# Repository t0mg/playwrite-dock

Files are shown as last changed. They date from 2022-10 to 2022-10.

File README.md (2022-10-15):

# Playwrite dock

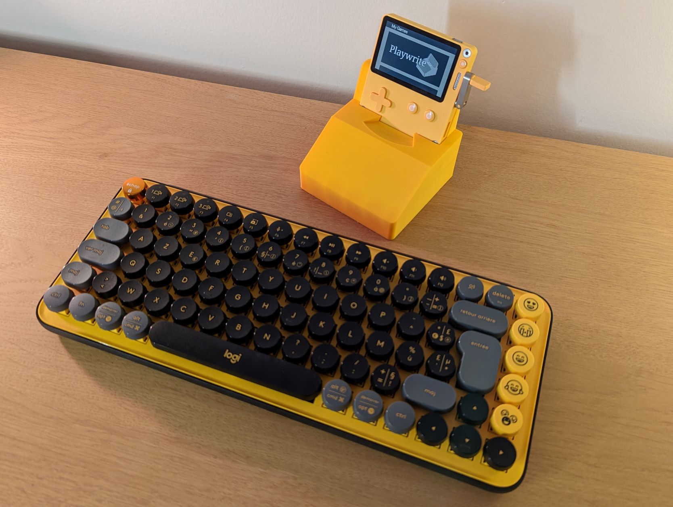
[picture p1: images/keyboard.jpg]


A keyboard and gamepad adapter dock for [Playdate](https://play.date), mainly designed for use with the [Playwrite experimental word processor](https://github.com/t0mg/playwrite), but compatible with any other Playdate game or app.

**Overview thread with demo videos: https://twitter.com/t0m_fr/status/1576949261849149440**

This repo is dedicated to the dock; it contains: 
- Source code for the Teensy microcontroller board (as a PlatformIO project)
- CAD and STL files for the 3d-printed dock (see [here](https://github.com/t0mg/playwrite-dock/tree/master/dock) for pictures and instructions)

For the Playwrite app for Playdate, see [here](https://github.com/t0mg/playwrite).

## Dock overview

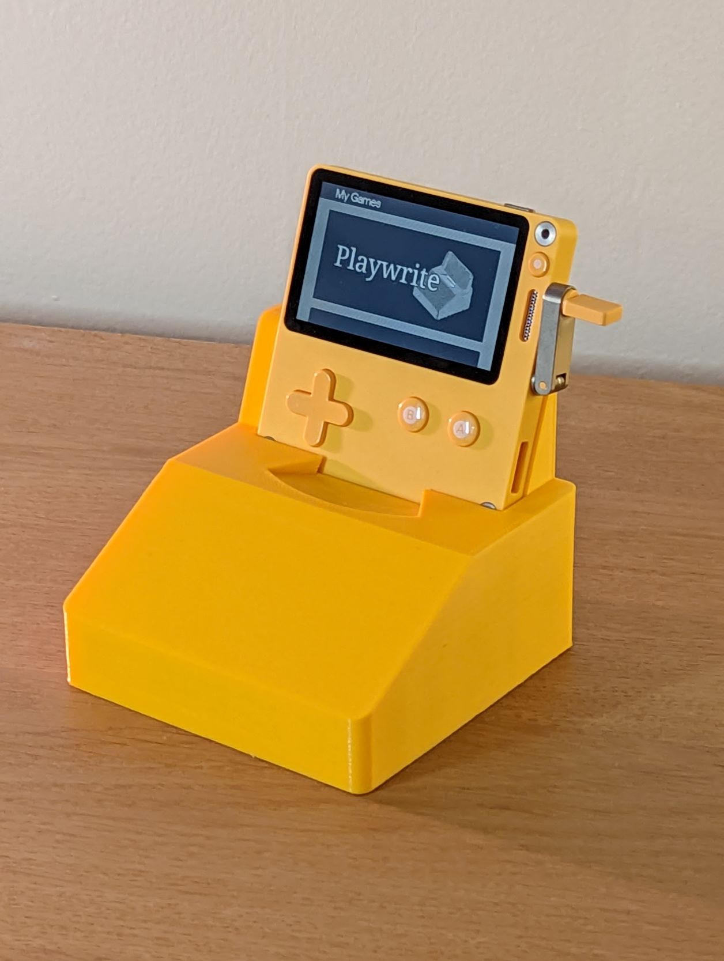
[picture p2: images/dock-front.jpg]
Bottom view of the dock assembly.
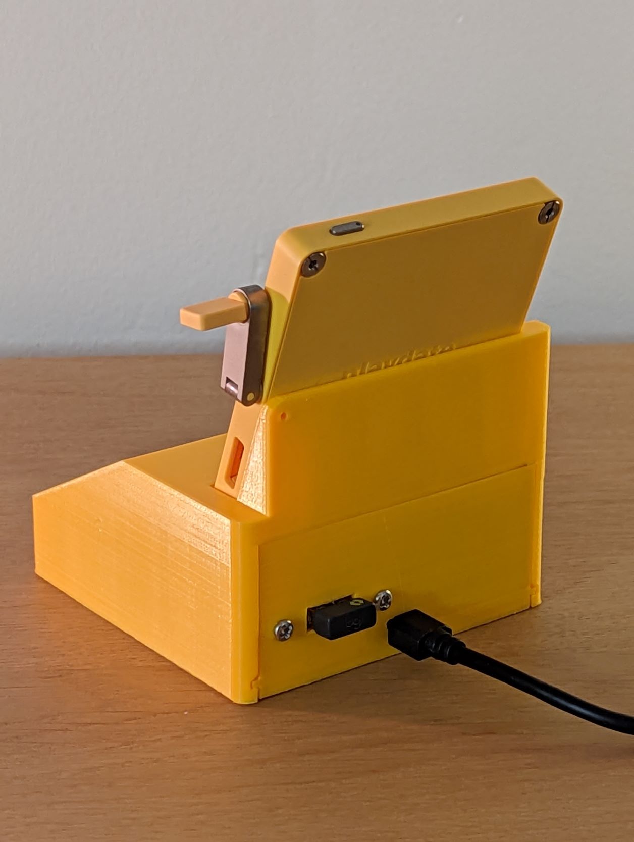
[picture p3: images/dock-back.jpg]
Bottom view of the dock assembly.
  

The dock is powered by a [Teensy 4.1 microcontroller](https://www.pjrc.com/store/teensy41.html). The USB Host port of the Teensy is used to connect to both a [Playdate](https://play.date/) console and a USB HID keyboard (or gamepad). It reads user inputs from these devices and uses USB Serial to communicate with the Playdate, leveraging a few of the available [USB commands](https://github.com/jaames/playdate-reverse-engineering/blob/main/usb/usb.md#usb-commands) to emulate native inputs, and listening to messages from the Playdate and [Playwrite app]((https://github.com/t0mg/playwrite)). 

The micro USB port of the Teensy is used to power the dock and flash the software. The dock also charges the Playdate though the Teensy (albeit slowly).

## Keyboard in controller mode

Arrow keys, Enter and Escape are directly mapped to the directions, A and B buttons respectively (and so are the A and S keys when not in the dedicated [Playwrite app](https://github.com/t0mg/playwrite). So the keyboard can be used anywhere in the OS or in games that don't rely on the crank (not because it's unusable; but because it's just not convenient).

## Full keyboard mode

The Playwrite app sends a specific command to the serial console (`KeyboardInputEnable`) to let the Teensy know that it can enable the "keyboard mode". In this mode,  keyspresses are encoded as `crankchange` angles in the dock (and decoded back to chars in the Playwrite app on the Playdate).

## USB Gamepad

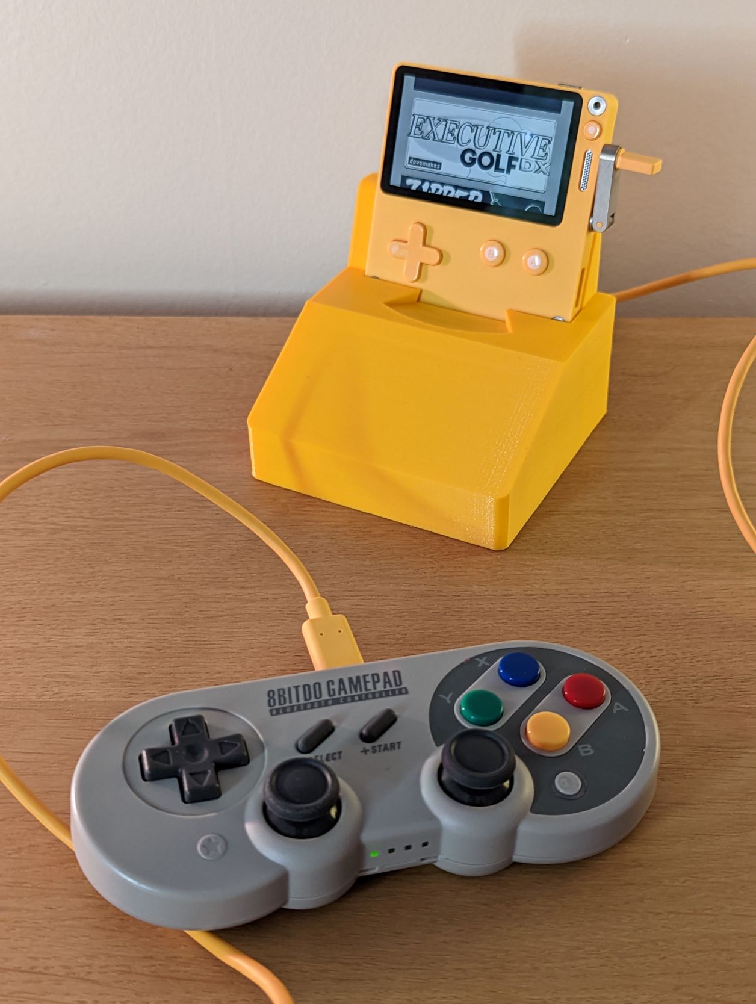
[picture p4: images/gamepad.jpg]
The dock connected over USB to an 8bitdo gamepad.


The dock software also supports USB Gamepads to some extent (tested on a couple of 8bitdo devices). This part of the project might arguably the most generally useful, as it could improve accessiblity of the device without the need of a full computer. 

TODO: Cranking via the gamepad is not supported. Mapping the right analog stick to the crank would be nice.

TODO: Bluetooth is not supported but is likely doable thanks to the [USBHost_t36](https://github.com/PaulStoffregen/USBHost_t36) library.

## BOM

It's a relatively cheap project. You'll need:

- A Teensy 4.1 microcontroller, with 4 pin header solderd to the USB Host port
- A USB 2.0 Hub
- Cables to connect your USB devices (Playdate, keyboard)

The exact references I used are linked in the [dock assembly page](https://github.com/t0mg/playwrite-dock/tree/master/dock#readme).

Additionally you'll need access to a 3d printer if you want to print the dock itself.

## Credits

Made possible by
- https://github.com/jaames/playdate-reverse-engineering
- https://www.pjrc.com/store/teensy41.html

Dependencies
- [USBHost_t36](https://github.com/PaulStoffregen/USBHost_t36) library
- [CircularBuffer](https://github.com/rlogiacco/CircularBuffer) library

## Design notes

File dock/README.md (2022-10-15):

# Playwrite dock CAD files

This folder contains the FCStd ([FreeCAD](https://www.freecadweb.org/)) [project file](https://github.com/t0mg/playwrite-dock/blob/master/dock/playwrite%20dock.FCStd) for the dock, as well as 3 STL exports (one for each part) ready for slicing.

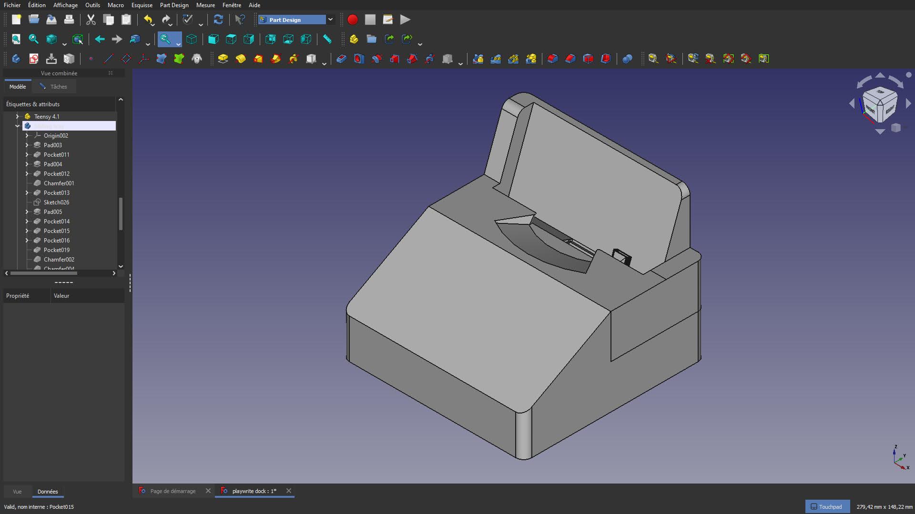
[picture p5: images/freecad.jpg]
FreeCAD screenshot.


## Printing

I loaded the 3 STL files into Cura and sliced them as a single print job, at 0.2mm layers using AA0.8 print core for support and AA0.4 core for the parts. It took 9 hours on an Ultimaker 3. Regardless of your printer and settings, supports are necessary for this print.

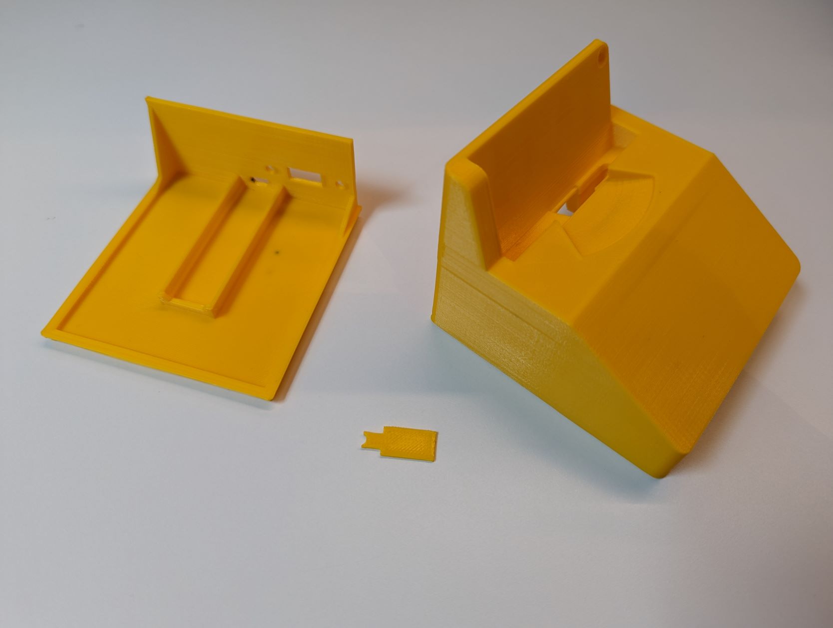
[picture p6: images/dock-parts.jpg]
The 3 parts of the dock, printed and cleaned up.


## Assembly

The project is designed to be very easy to assemble. The dock could be made quite a bit slimmer by using custom-built cables at the cost of requiring a lot more soldering.

### 1. USB C connector

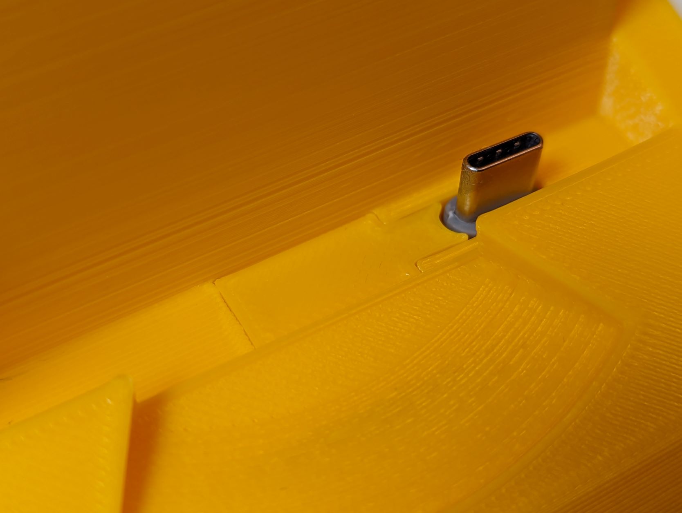
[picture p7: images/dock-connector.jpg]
Close-up view of the USB C connector protruding from the assembled dock.


This dock was designed specifically for [this USB A to angled USB C cable](https://www.amazon.fr/gp/product/B07H95NY5Y). The USB C male connector slides in the dedicated slot in the main part of the dock, then the small cover piece can be press-fit from the top to hide the opening.
    
### 2. Teensy

The bottom tray is designed to host the [Teensy 4.1](https://www.pjrc.com/store/teensy41.html) development board. It's a snug fit, insert the USB connector into the hole first, then press the Teensy down into the tray. Access the SD card slot was preserved, even though this project doesn't use it. You'll need to solder a 4 pin header connector to the USB host port prior to installing the Teensy.

### 3. USB hub

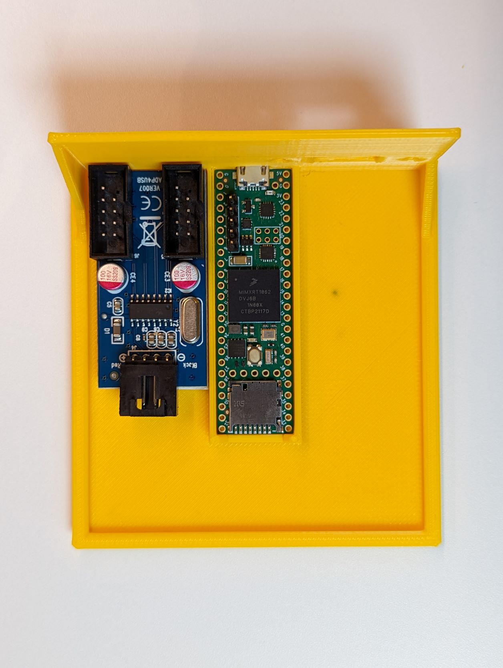
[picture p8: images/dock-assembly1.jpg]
The Teensy and USB C hub sitting in the bottom tray of the dock.


To connect more than 1 device at a time, I used [this USB 2.0 Hub](https://www.amazon.fr/gp/product/B088H6221R) intended for desktop PCs, which connects to the Teensy header. It came with doublesided tape, which makes positioning it in the dock tray very straightforward.

### 4. USB sockets

Finally I used [standard USB extension ports](https://www.amazon.fr/gp/product/B06XCVSPZ1) also meant for desktop PCs. You only need one of these cables since they have 2 USB connectors each. One goes to the tray's backplate and is held by the 2 original screws, it will host the gamepad or keyboard. The other remains inside the dock and connects to the Playdate via the USB A to USB C cable. The tray can then be slid into the upper piece of the dock (no locking system, it is tight enough to hold in place by itself).

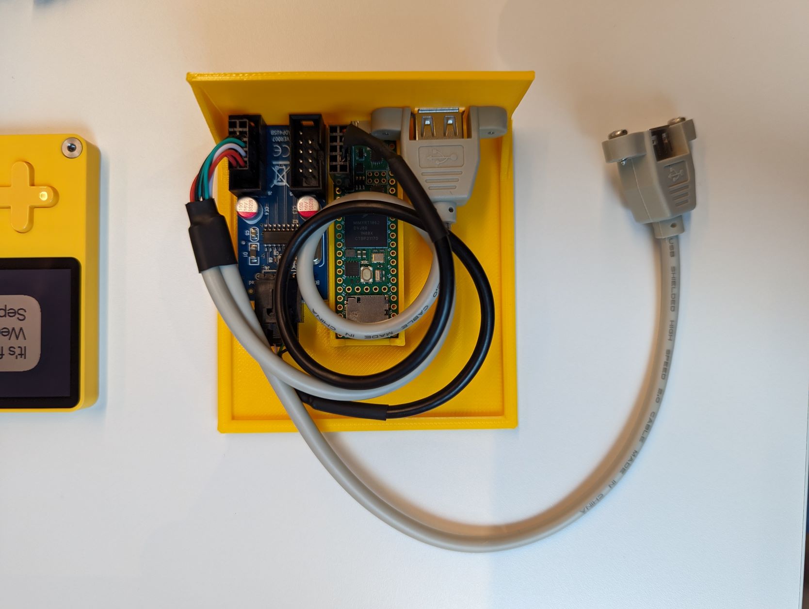
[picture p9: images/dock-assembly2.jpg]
Closing the tray under the dock.
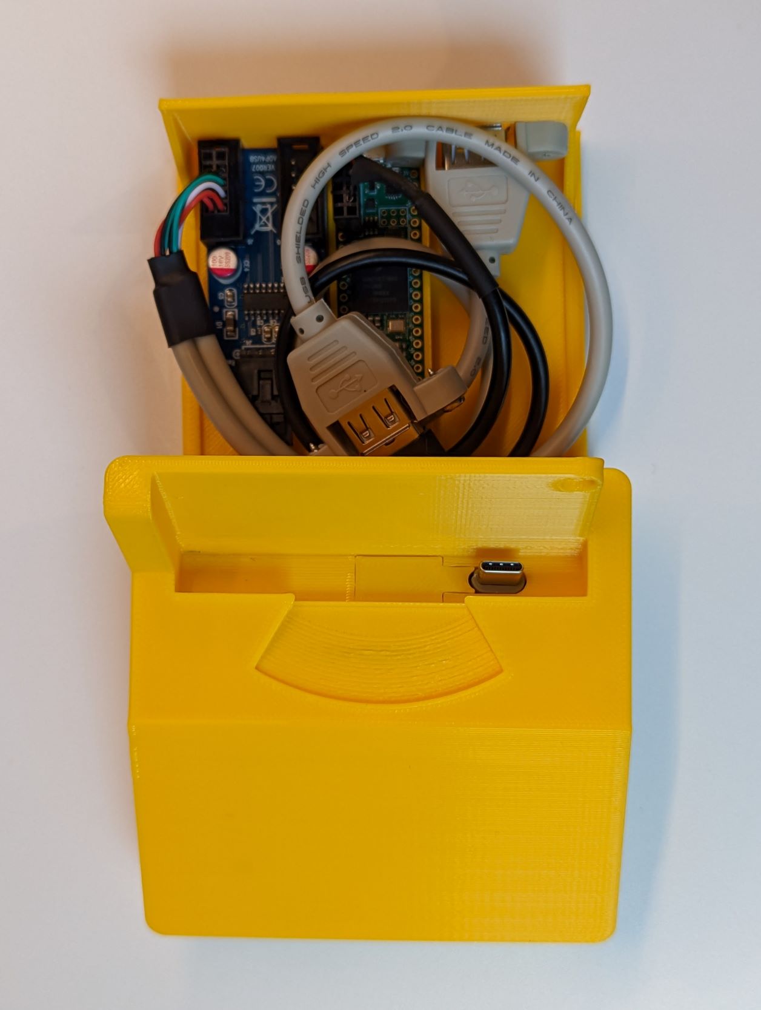
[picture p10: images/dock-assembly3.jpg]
USB cables installed in the tray.
 

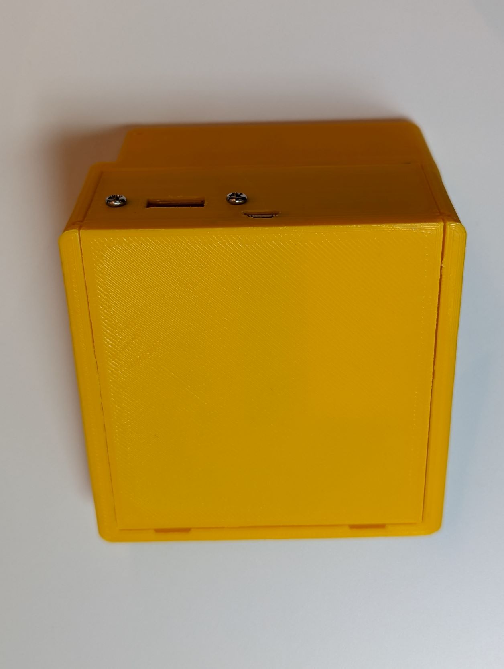
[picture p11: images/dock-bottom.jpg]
Bottom view of the dock assembly.
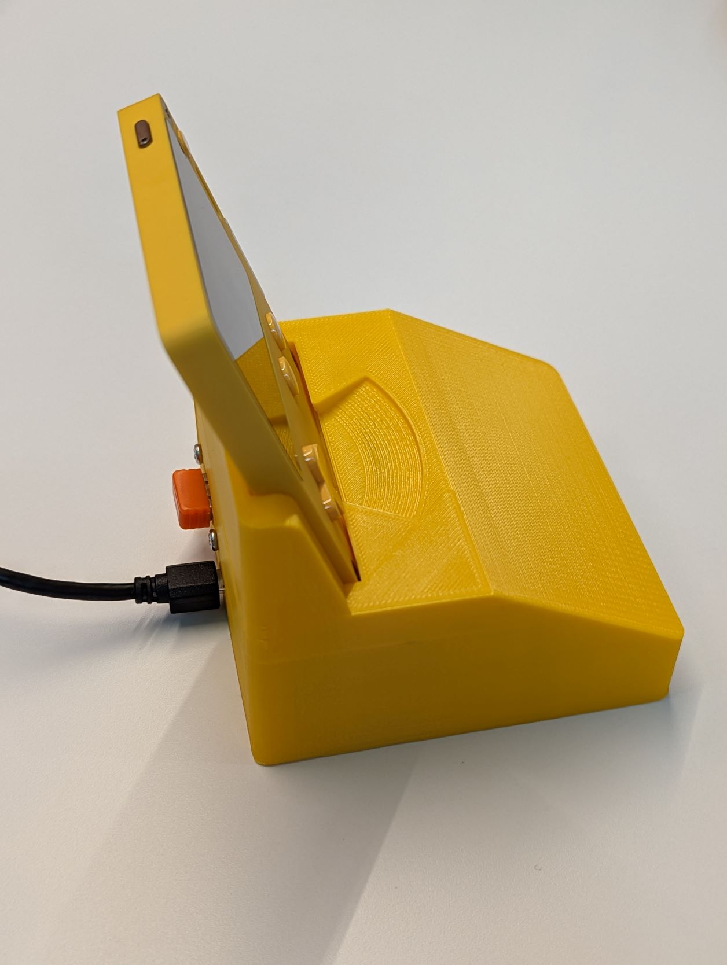
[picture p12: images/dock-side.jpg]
Side view of the dock assembly.
 

### Credits

- [Teensy 4.1 model by Hasanain Shuja](https://grabcad.com/library/teensy-4-1-2)

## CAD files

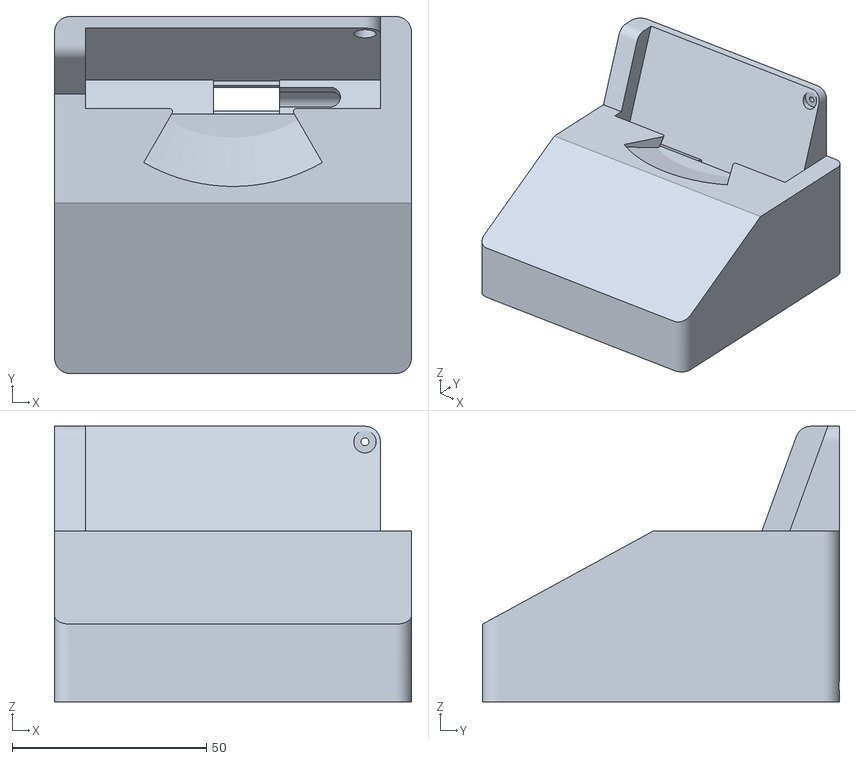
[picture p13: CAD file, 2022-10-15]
dock/playwrite dock-Dock body.stl
92.0 x 92.0 x 71.0

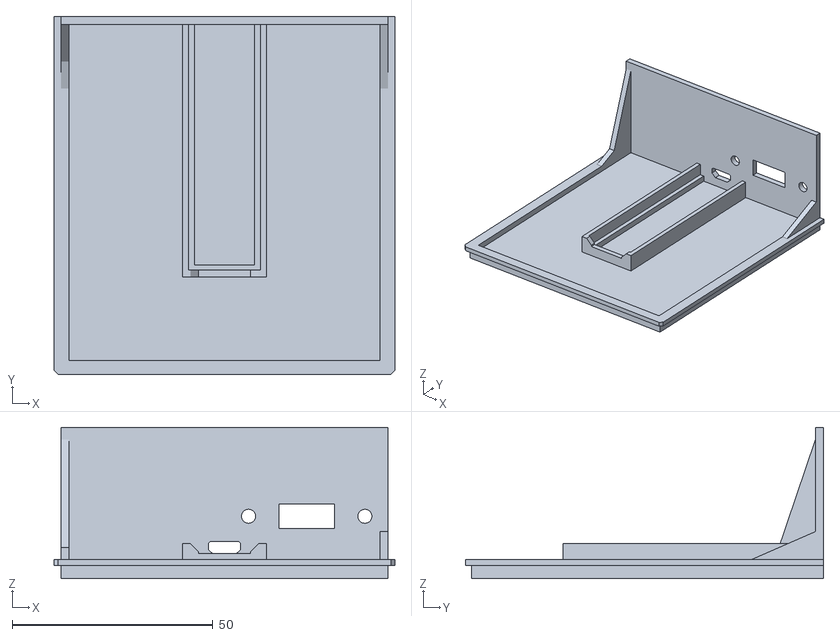
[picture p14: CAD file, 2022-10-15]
dock/playwrite dock-Sliding tray.stl
85.0 x 89.2 x 37.8

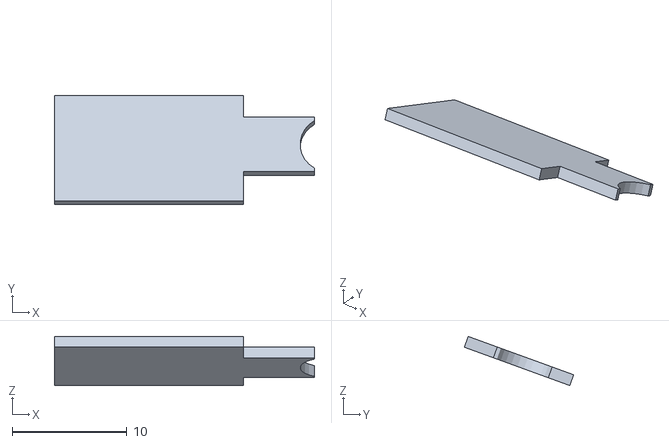
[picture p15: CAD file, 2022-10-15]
dock/playwrite dock-Cap.stl
22.7 x 9.55 x 4.29

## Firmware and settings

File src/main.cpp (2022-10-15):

// Playwrite dock software (for Teenzy 4.1)
// part of the Playwrite project 
#include <Arduino.h>
#include "USBHost_t36.h"
#include "CircularBuffer.h"
// #define DEBUG 1

#ifdef DEBUG
#define DEBUG_PRINT(x) Serial.println(x)
#else
#define DEBUG_PRINT(x)
#endif

const char *PLAYDATE_KEYBOARD_ENABLE_MESSAGE = "KeyboardInputEnable";
const char *PLAYDATE_KEYBOARD_DISABLE_MESSAGE = "KeyboardInputDisable";
const char *PLAYDATE_READY_FOR_KEYSTROKE_MESSAGE = "ReadyForNextInput";
const int PLAYDATE_KEYBOARD_INPUT_ANGLE_OFFSET = 100;

const char *PLAYDATE_PRODUCT_NAME = "Playdate";
const unsigned int MAX_INPUT = 50;
uint32_t baud = 115200;
USBHost myusb;
USBHub hub1(myusb);
KeyboardController keyboard1(myusb);
JoystickController joystick1(myusb);
USBHIDParser hid1(myusb);
USBHIDParser hid2(myusb);
USBSerial_BigBuffer userial(myusb, 1);

USBDriver *drivers[] = {&hub1, &hid1, &hid2, &userial};
#define CNT_DEVICES (sizeof(drivers) / sizeof(drivers[0]))
const char *driver_names[CNT_DEVICES] = {"Hub1", "HID1", "HID2", "USERIAL1"};
bool driver_active[CNT_DEVICES] = {false, false, false, false};

// Lets also look at HID Input devices
USBHIDInput *hiddrivers[] = {&keyboard1, &joystick1};
#define CNT_HIDDEVICES (sizeof(hiddrivers) / sizeof(hiddrivers[0]))
const char *hid_driver_names[CNT_HIDDEVICES] = {"Keyboard", "Joystick"};
bool hid_driver_active[CNT_HIDDEVICES] = {false, false};

CircularBuffer<String, 100> playdateMessageQueue;
bool playdateReadyForKeyboard = false;
bool playdateBusy = false;

void ShowUpdatedDeviceListInfo()
{
  for (uint8_t i = 0; i < CNT_DEVICES; i++)
  {
    if (*drivers[i] != driver_active[i])
    {
      if (driver_active[i])
      {
#ifdef DEBUG
        Serial.printf("*** Device %s - disconnected ***\n", driver_names[i]);
#endif
        driver_active[i] = false;
      }
      else
      {
        driver_active[i] = true;
        const uint8_t *product = drivers[i]->product();
#ifdef DEBUG
        Serial.printf("*** Device %s %x:%x - connected ***\n", driver_names[i], drivers[i]->idVendor(), drivers[i]->idProduct());
        const uint8_t *psz = drivers[i]->manufacturer();
        if (psz && *psz)
          Serial.printf("  manufacturer: %s\n", psz);
        if (product && *product)
          Serial.printf("  product: %s\n", product);
        psz = drivers[i]->serialNumber();
        if (psz && *psz)
          Serial.printf("  Serial: %s\n", psz);
#endif

        // Note: with some keyboards there is an issue that they don't output in boot protocol mode
        // and may not work.  The above code can try to force the keyboard into boot mode, but there
        // are issues with doing this blindly with combo devices like wireless keyboard/mouse, which
        // may cause the mouse to not work.  Note: the above id is in the builtin list of
        // vendor IDs that are already forced
        //         if (drivers[i] == &keyboard1)
        //         {
        //           if (keyboard1.idVendor() == 0x04D9) // 0x46D
        //           {
        // #ifdef DEBUG
        //             Serial.println("Gigabyte vendor: force boot protocol");
        // #endif
        //             // Gigabyte keyboard
        //             keyboard1.forceBootProtocol();
        //           }
        //         }
        // If this is a new Serial device.
        if (drivers[i] == &userial && strcmp((const char *)product, PLAYDATE_PRODUCT_NAME) == 0)
        {
#ifdef DEBUG
          Serial.println("\n  Connected to Playdate Serial, yay!");
#endif
          // Lets try first outputting something to our USerial to see if it will go out...
          userial.begin(baud);
        }
      }
    }
  }
  // Then Hid Devices
  for (uint8_t i = 0; i < CNT_HIDDEVICES; i++)
  {
    if (*hiddrivers[i] != hid_driver_active[i])
    {
      if (hid_driver_active[i])
      {
        Serial.printf("*** HID Device %s - disconnected ***\n", hid_driver_names[i]);
        hid_driver_active[i] = false;
      }
      else
      {
        const uint8_t *product = hiddrivers[i]->product();
        Serial.printf("*** HID Device %s %x:%x - connected ***\n", hid_driver_names[i], hiddrivers[i]->idVendor(), hiddrivers[i]->idProduct());
        hid_driver_active[i] = true;
        const uint8_t *psz = hiddrivers[i]->manufacturer();
        if (psz && *psz)
          Serial.printf("  manufacturer: %s\n", psz);
        if (product && *product)
        {
          Serial.printf("  product: %s\n", product);
        }
        psz = drivers[i]->serialNumber();
        if (psz && *psz)
          Serial.printf("  Serial: %s\n", psz);
        // keyboard1.forceBootProtocol();
      }
    }
  }
}

void OnPress(int key)
{
  // Exit early if keyboard mode isn't enabled.
  if (!playdateReadyForKeyboard)
  {
    return;
  }

  // Arrow keys handled by raw callbacks
  if (key >= 215 && key <= 218)
  {
    return;
  }

  // Also ignore Esc, Return, Backspace, Delete, Caps lock
  if (key == 27 || key == 10 || key == 127 || key == 212 || key == 0)
  {
    return;
  }

  Serial.print("\n\npressed ");
  Serial.print((char)key);
  Serial.print(" - ");
  Serial.println(key);

  if (playdateReadyForKeyboard && (key + PLAYDATE_KEYBOARD_INPUT_ANGLE_OFFSET) < 359)
  {
    Serial.print("changecrank ");
    Serial.println(key + PLAYDATE_KEYBOARD_INPUT_ANGLE_OFFSET);
    playdateMessageQueue.push("changecrank " + (String)(key + PLAYDATE_KEYBOARD_INPUT_ANGLE_OFFSET));
    //userial.print("changecrank ");
    //userial.println(key + 32); 
  }
  // Serial.print("'  ");
  // Serial.print(key);
  // Serial.print(" MOD: ");
  // Serial.print(keyboard1.getModifiers(), HEX);
  // Serial.print(" OEM: ");
  // Serial.print(keyboard1.getOemKey(), HEX);
  // Serial.print(" LEDS: ");
  // Serial.println(keyboard1.LEDS(), HEX);
}

#define RAW_RIGHT_ARROW 0x4F
#define RAW_LEFT_ARROW 0x50
#define RAW_DOWN_ARROW 0x51
#define RAW_UP_ARROW 0x52
#define RAW_ENTER 0x28
#define RAW_BACKSPACE 0x2a
#define RAW_ESCAPE 0x29

String rawKeyToBtn(uint8_t keycode)
{
  if (!playdateReadyForKeyboard)
  {
    switch (keycode)
    {
    case 0x16: // S key
      return "a";
      break;
    case 0x04: // A key in QWERTY
    case 0x14: // A key in AZERTY
      return "b";
      break;
    }
  }
  switch (keycode)
  {
  case RAW_RIGHT_ARROW:
    return "right";
    break;
  case RAW_LEFT_ARROW:
    return "left";
    break;
  case RAW_DOWN_ARROW:
    return "down";
    break;
  case RAW_UP_ARROW:
    return "up";
    break;
  case RAW_ENTER:
    return "a";
    break;
  case RAW_BACKSPACE:
    return "b";
    break;
  case RAW_ESCAPE:
    return "menu";
    break;
  default:
    return "n/a";
    break;
  }
}

void OnRawPress(uint8_t keycode)
{
#ifdef DEBUG
  Serial.println();
  Serial.print("raw press ");
  Serial.println(keycode);
#endif
  String pd = rawKeyToBtn(keycode);
  if (pd != "n/a")
  {
    userial.println("btn +" + (String)pd);
    DEBUG_PRINT(" >> btn +" + (String)pd);
  }
}

void OnRawRelease(uint8_t keycode)
{
#ifdef DEBUG
  Serial.println();
  Serial.print("raw release ");
  Serial.println(keycode);
#endif
  String pd = rawKeyToBtn(keycode);
  if (pd != "n/a")
  {
    userial.println("btn -" + (String)pd);
    DEBUG_PRINT(" >> btn -" + (String)pd);
  }
}

void process_data(const char *data)
{
  Serial.print("[Playdate says] ");
  Serial.println(data);
  if (strcmp(data, PLAYDATE_READY_FOR_KEYSTROKE_MESSAGE) == 0)
  {
    playdateBusy = false;
  }
  if (strcmp(data, PLAYDATE_KEYBOARD_ENABLE_MESSAGE) == 0)
  {
    playdateReadyForKeyboard = true;
#ifdef DEBUG
    digitalWrite(13, HIGH);
    Serial.println("Enabling keyboard input forwarding");
#endif
  }
  else if (strcmp(data, PLAYDATE_KEYBOARD_DISABLE_MESSAGE) == 0)
  {
    playdateReadyForKeyboard = false;
#ifdef DEBUG
    digitalWrite(13, LOW);
    Serial.println("Disabling keyboard input forwarding");
#endif
  }
}

// from http://www.gammon.com.au/serial
void processIncomingByte(const byte inByte)
{
  static char input_line[MAX_INPUT];
  static unsigned int input_pos = 0;

  switch (inByte)
  {
  case '\n':                   // end of text
    input_line[input_pos] = 0; // terminating null byte
    // terminator reached! process input_line here ...
    process_data(input_line);
    // reset buffer for next time
    input_pos = 0;
    break;
  case '\r': // discard carriage return
    break;
  default:
    // keep adding if not full ... allow for terminating null byte
    if (input_pos < (MAX_INPUT - 1))
      input_line[input_pos++] = inByte;
    break;
  } // end of switch

} // end of processIncomingByte

void setup()
{
  pinMode(13, OUTPUT);
  myusb.begin();
#ifdef DEBUG
  while (!Serial)
    ; // wait for Arduino Serial Monitor
  Serial.println("\n\nPLaydate Serial Adapter - debug mode");
  // Serial.println(sizeof(USBHub), DEC);
#endif
  keyboard1.attachPress(OnPress);
  keyboard1.attachRawPress(OnRawPress);
  keyboard1.attachRawRelease(OnRawRelease);

  // Only notify basic axis changes
  joystick1.axisChangeNotifyMask(0x3ff);
}

uint32_t prevButtons = 0;

enum IAXIS
{
  AXIS_UP = 0,
  AXIS_DOWN,
  AXIS_LEFT,
  AXIS_RIGHT
};
bool prevAxis9[4] = {false, false, false, false};

void processButton(uint32_t buttons, uint32_t prev, u_int32_t mask, String key)
{
  if ((buttons & mask))
  {
    if (!(prevButtons & mask))
    {
      userial.println("btn +" + key);
      Serial.println("btn +" + key);
    }
  }
  else if (prevButtons & mask)
  {
    userial.println("btn -" + key);
    Serial.println("btn -" + key);
  }
}

void processAxis(int axisValue, String lowValue, String highValue)
{
  if (axisValue == 0)
  {
    userial.println("btn +" + lowValue);
    Serial.println("btn +" + lowValue);
  }
  else if (axisValue == 255)
  {
    userial.println("btn +" + highValue);
    Serial.println("btn +" + highValue);
  }
  else if (axisValue == 128)
  {
    userial.println("btn -" + lowValue);
    Serial.println("btn -" + lowValue);
    userial.println("btn -" + highValue);
    Serial.println("btn -" + highValue);
  }
}

void process8bitdoAxis(int axisValue)
{
  bool axis9[4] = {false, false, false, false};
  axis9[AXIS_UP] = axisValue == 7 || axisValue == 0 || axisValue == 1;
  axis9[AXIS_RIGHT] = axisValue == 1 || axisValue == 2 || axisValue == 3;
  axis9[AXIS_DOWN] = axisValue == 3 || axisValue == 4 || axisValue == 5;
  axis9[AXIS_LEFT] = axisValue == 5 || axisValue == 6 || axisValue == 7;
  for (int i = 0; i < 4; i++)
  {
    if (axis9[i] != prevAxis9[i])
    {
      String key;
      switch (i)
      {
      case AXIS_UP:
        key = "up";
        break;
      case AXIS_DOWN:
        key = "down";
        break;
      case AXIS_LEFT:
        key = "left";
        break;
      case AXIS_RIGHT:
        key = "right";
        break;
      }
      if (axis9[i] == true)
      {
        userial.println("btn +" + key);
        DEBUG_PRINT("btn +" + key);
      }
      else
      {
        userial.println("btn -" + key);
        DEBUG_PRINT("btn -" + key);
      }
      prevAxis9[i] = axis9[i];
    }
  }
}

void loop()
{
  myusb.Task();
  ShowUpdatedDeviceListInfo();

#ifdef DEBUG
  if (Serial.available())
  {
    int ch = Serial.read(); // get the first char.
    while (Serial.read() != -1)
      ;
    if ((ch == 'k') || (ch == 'K'))
    {
      Serial.print("Toggle keyboard mode: ");
      playdateReadyForKeyboard = !playdateReadyForKeyboard;
      Serial.println(playdateReadyForKeyboard);
    }
  }
#endif

  while (userial.available() > 0)
    processIncomingByte(userial.read());

  if (joystick1.available() && joystick1.joystickType() != JoystickController::PS4)
  {
    // switch (joystick1.joystickType()) {
    // case JoystickController::PS4:
    // case JoystickController::PS3:
    // case JoystickController::XBOXONE:
    // case JoystickController::XBOX360:
    // }
    uint64_t axis_changed_mask = joystick1.axisChangedMask();
    uint32_t buttons = joystick1.getButtons();
    processButton(buttons, prevButtons, 0x0001, "a");    // A
    processButton(buttons, prevButtons, 0x0008, "b");    // X
    processButton(buttons, prevButtons, 0x0002, "b");    // B
    processButton(buttons, prevButtons, 0x0010, "a");    // Y
    processButton(buttons, prevButtons, 0x0800, "menu"); // Start
    processButton(buttons, prevButtons, 0x0400, "lock"); // Select

    for (uint8_t i = 0; axis_changed_mask != 0; i++, axis_changed_mask >>= 1)
    {
      if (axis_changed_mask & 1)
      {
        int axisValue = joystick1.getAxis(i);
        Serial.printf(" %d:%d", i, axisValue);
        switch (i)
        {
        case 0:
          processAxis(axisValue, "left", "right");
          break;
        case 1:
          processAxis(axisValue, "up", "down");
          break;
        case 9:
          process8bitdoAxis(axisValue);
          break;
        }
      }
    }
    prevButtons = buttons;
    joystick1.joystickDataClear();
  }

  if (!playdateBusy && !playdateMessageQueue.isEmpty())
  {
    playdateBusy = true;
    userial.println(playdateMessageQueue.shift());
  }
}

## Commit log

2022-10-15 add images for dock assembly
2022-10-15 Add details about dock assembly
2022-10-15 Update README.md
    add minimal BOM section
